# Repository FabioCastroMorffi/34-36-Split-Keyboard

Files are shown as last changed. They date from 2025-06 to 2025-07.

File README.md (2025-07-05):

# Raw Split
## Overview

Raw Split is a wired 36 key split keyboard made with 3 PCB layers and powered by an RP pico 2040 on each side. I'm using the Miryoku ZMK as the layout and  I decided to go for a smaller split keyboard for two main reasons: I want it to be portable, mainly so I can use it in class, and I wanted to be under (or very close to) the 50$ mark.

## Motivation
After finishing my design for Hackpad, which was an introduction to PCB Design and 3D modelling, I was confident I could go build a bigger project in a more efficient manner but I was completely wrong. I got sent to the Valley of Stupidity earlier than expected. 

I had an initial idea with a Split Keyboard that would have magnetic sides but I wasn't proud of the design I came up with (and it wasnt printable) so I decided to scrap it up and do it again with a different idea. The change was mainly on the fact that I abhorred 3D modelling of the top/side and bottom so on the Raw Split I decided to only use PCBs for the full design; the raw aesthetic of the build is where the name comes from -- I'm not very creative with names.

## PCBs

### Center

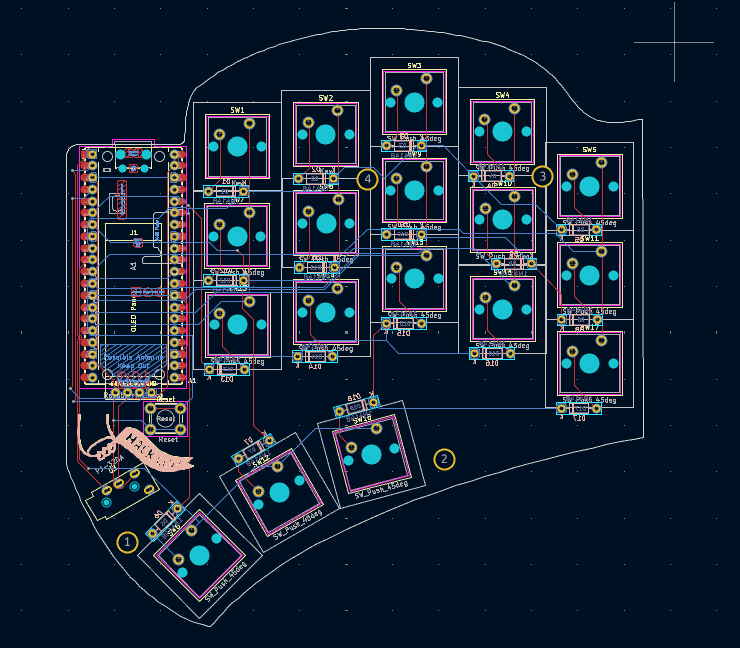
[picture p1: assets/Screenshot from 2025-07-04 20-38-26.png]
Center

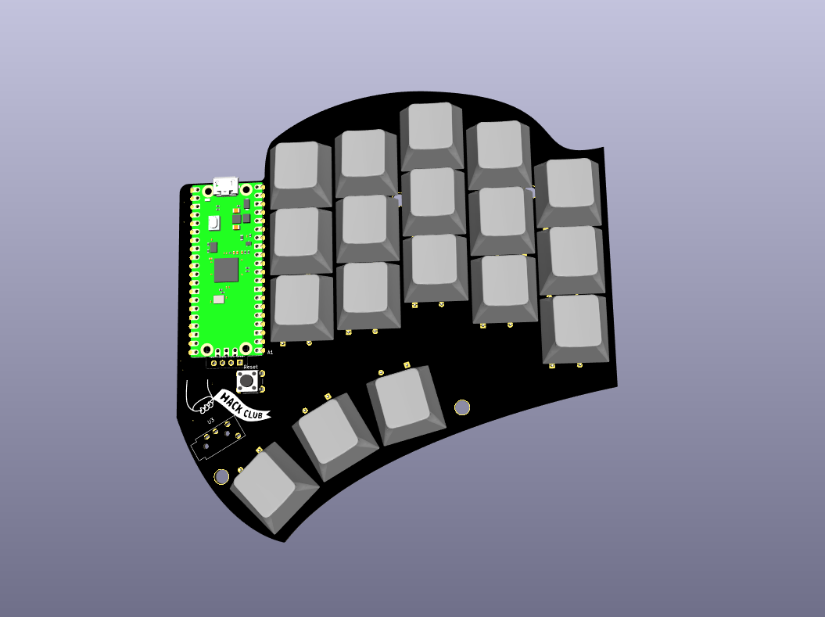
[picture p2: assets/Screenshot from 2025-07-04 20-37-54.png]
3d center


### Top
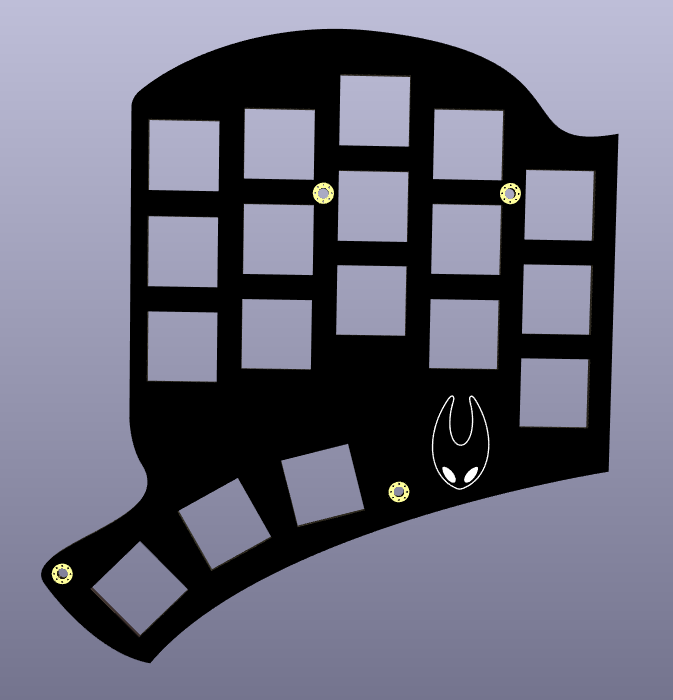
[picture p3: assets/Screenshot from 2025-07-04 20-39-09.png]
Top


### Bottom

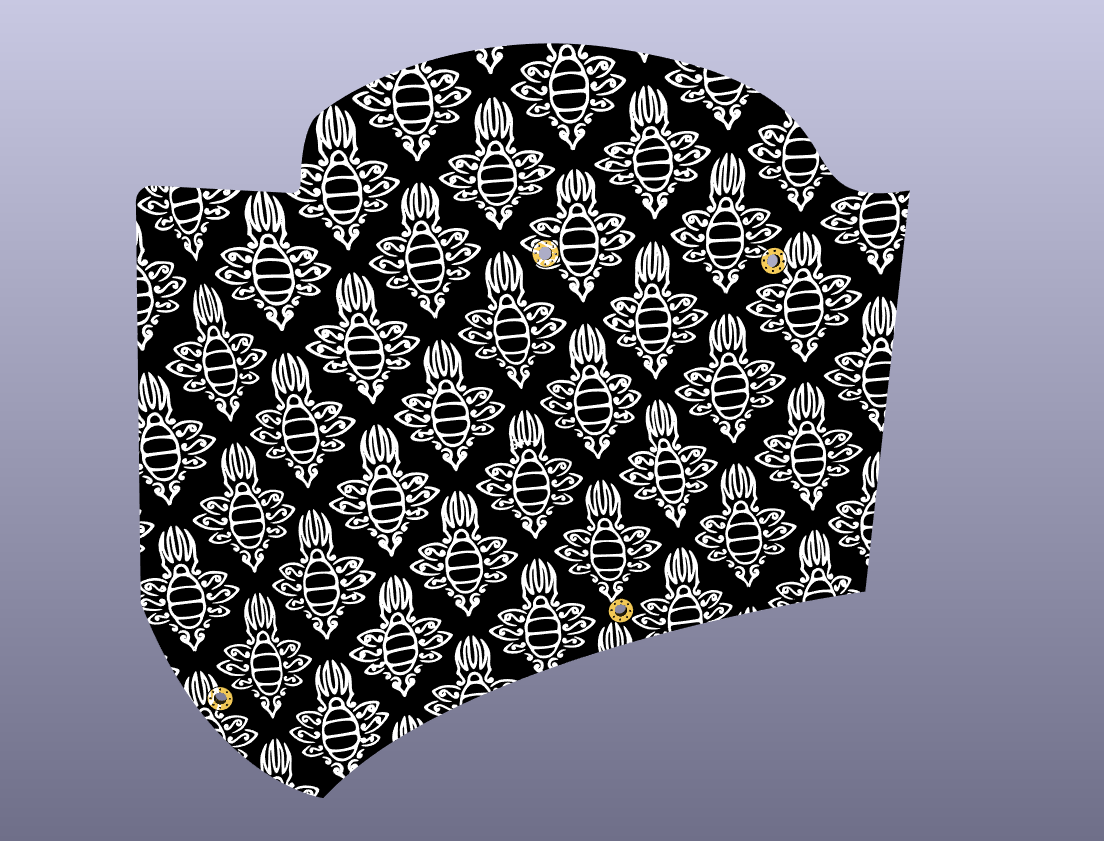
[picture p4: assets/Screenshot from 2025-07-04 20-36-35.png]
Bottom


## CAD
[Direct link on Onshape](https://cad.onshape.com/documents/60adbd5316aad71d4d3bcb16/w/73c77201f5fbc04cf68d7350/e/32bb371216fb4a7634cbbee2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)

Thank you Onshape for being so easy to work with (shame on the horrible experience that is Fusion360's online services for students). I really need to emphasize how much better OnShape is on web, because the initial horrible experience I had with Fusion Online or trying to install a Linux version of Fusion was horrible and made me waste a lot of time. 

Here's the overview of the right split:

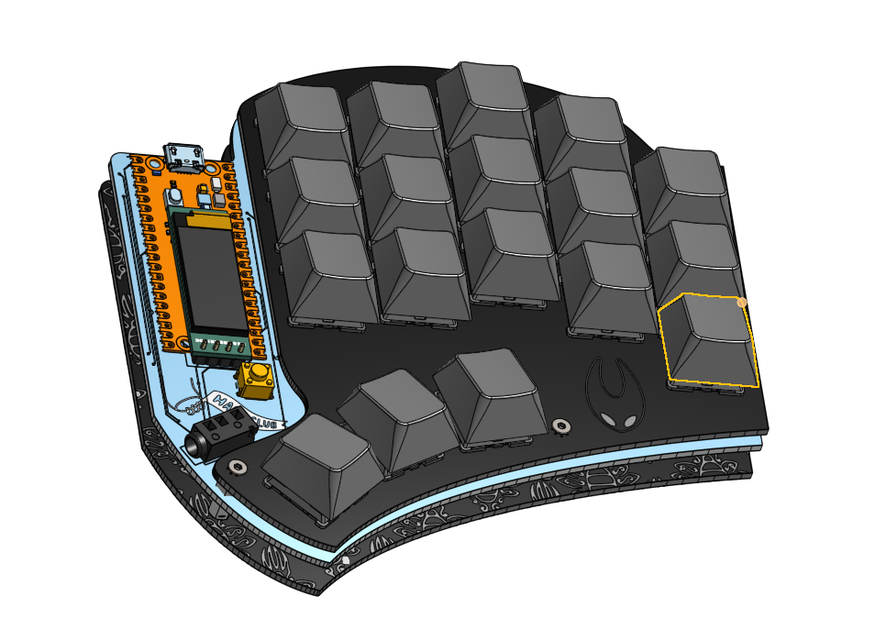
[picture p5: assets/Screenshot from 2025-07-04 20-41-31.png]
Overview


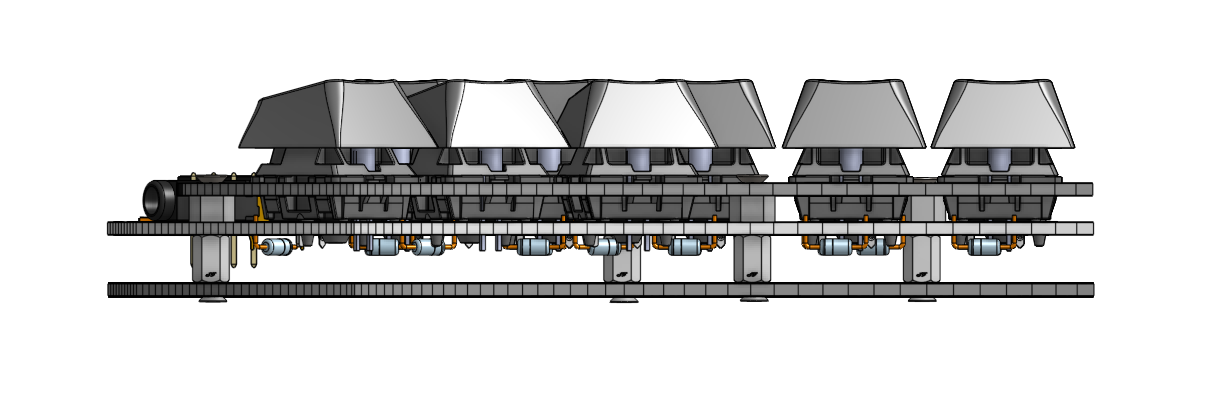
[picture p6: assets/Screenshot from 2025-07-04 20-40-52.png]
Side View


The total height of the keyboard will be 24.8 mm. The three PCBs measure 1.6 mm in height, the small standoff will have a height of 4 mm while the big one will have a size 6 mm. Finally the height from the top plate to the top of the keycap is approximally 10 mm. 

## BOM

| Quantity | Item | Price (CAD) | Vendor | Link |
|---|---|---|---|---|
| 2 | RP Pico 2040 Green with Pin | 6.42 | Aliexpress | [Link](https://shorturl.at/I2swX) |
| 1 | 40 PCS kailh box V2 (linear switches)| 1.38(with welcome deal) | Aliexpress | [Link](https://www.aliexpress.com/item/1005005704076690.html) | 
| 1 | 100 PCS Through Hole Diodes (1N4148) | 2.80 | Aliexpress | [Link](https://shorturl.at/UQSGh) |
| 2 | 0.91 Inch 128x32 Oled Display | 5.00 | Aliexpress | [Link](https://www.aliexpress.com/item/32709141534.html) |
| 2 | 20 pcs Blank DSA Keycaps | 12.5 | Aliexpress | [link](https://shorturl.at/4GHxS) |
| 1 | 10 PCS PJ-320A Jack Receptacle | 1.58 | Aliexpress | [Link](https://www.aliexpress.com/item/1005004960903273.html) |
| 1 | 20 pcs SW-Push 6x6x4.3mm | 0.26 | Aliexpress | [Link](https://shorturl.at/fNnse) |
| 1 | 50 pcs Brass Female to Female Standoffs M2x3mm | 2.72 | Aliexpress | [Link](https://shorturl.at/DMM1S)|
| 1 | 50 pcs Nylon Female to Female Standoffs M2x6mm | 1.28 | Aliexpress | [Link](https://shorturl.at/DEXHc)
| 2 | 50 pcs M2 5mm and M2 10 mm | 4.5 | Aliexpress | [Link](https://shorturl.at/Y6ADS) |
| 1 | Antislip Circular Pads 2mm | 2.97 | Aliexpress | [Link](https://shorturl.at/uavc9)
| 1 | PCB Manufacturing Center | 13.04  (without coupon) | JLCPCB | 
| 1 | PCB Manufacturing Top | 12.64  (without coupon) | JLCPCB |
| 1 | PCB Manufacturing Bottom | 12.50  (without coupon) | JLCPCB |

|Total (CAD, after taxes and after 20$ JLcPCB Coupon)| Total (USD, after taxes and after 20$ JLcPCB Coupon)|
|---|--|
|69|50.69|

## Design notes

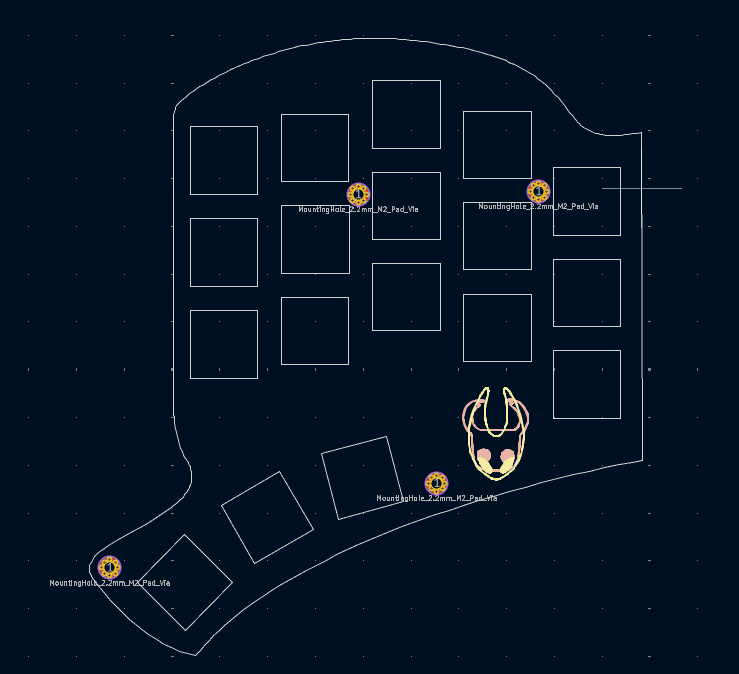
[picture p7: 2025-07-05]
assets/Screenshot from 2025-07-04 20-39-25.png

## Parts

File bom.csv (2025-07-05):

Quantity | Item | Price (CAD) | Vendor | Link | Total(CAD after taxes and after 20$ JLPCB Coupon) | Total(USD after taxes and after 20$ JLcPCB Coupon)
2 | RP Pico 2040 Green with Pin | 6.42 | Aliexpress | https://shorturl.at/I2swX
1 | 40 PCS kailh box V2 (linear switches) | 1.38 (with welcome deal) | Aliexpress | https://www.aliexpress.com/item/1005005704076690.html
1 | 100 PCS Through Hole Diodes (1N4148) | 2.80 | Aliexpress | https://shorturl.at/UQSGh
2 | 0.91 Inch 128x32 Oled Display | 5.00 | Aliexpress | https://www.aliexpress.com/item/32709141534.html
2 | 20 pcs Blank DSA Keycaps | 12.5 | Aliexpress | https://shorturl.at/4GHxS
1 | 10 PCS PJ-320A Jack Receptacle | 1.58 | Aliexpress | https://www.aliexpress.com/item/1005004960903273.html
1 | 20 pcs SW-Push 6x6x4.3mm | 0.26 | Aliexpress | https://shorturl.at/fNnse
1 | 50 pcs Brass Female to Female Standoffs M2x3mm | 2.72 | Aliexpress | https://shorturl.at/DMM1S
1 | 50 pcs Nylon Female to Female Standoffs M2x6mm | 1.28 | Aliexpress | https://shorturl.at/DEXHc
2 | 50 pcs M2 5mm and M2 10 mm | 4.5 | Aliexpress | https://shorturl.at/Y6ADS
1 | Antislip Circular Pads 2mm | 2.97 | Aliexpress | https://shorturl.at/uavc9
1 | PCB Manufacturing Center | 13.04 (without coupon) | JLCPCB
1 | PCB Manufacturing Top | 12.64 (without coupon) | JLCPCB
1 | PCB Manufacturing Bottom | 12.50 (without coupon) | JLCPCB
 |  |  |  |  | 69 | 50.69

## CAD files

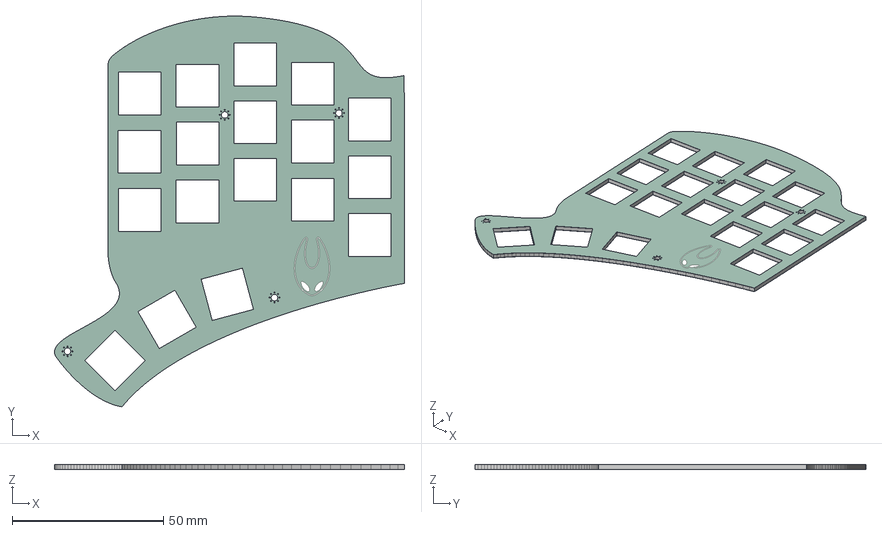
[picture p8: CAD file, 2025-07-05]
PCB/3d models/top.step
115.7 x 129.2 x 1.66 mm
top_silkscreen
top_soldermask
top_PCB

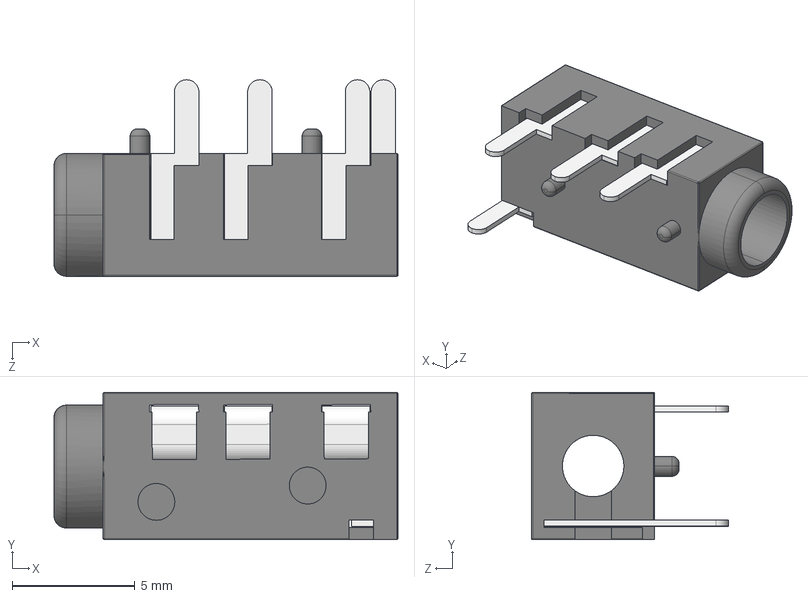
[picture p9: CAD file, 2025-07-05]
PCB/raw split center/3d models/PJ320A.STEP
14.0 x 6.00 x 8.00 mm
PJ320A
PJ320A-Pin x 3
PJ320A-Pin-B

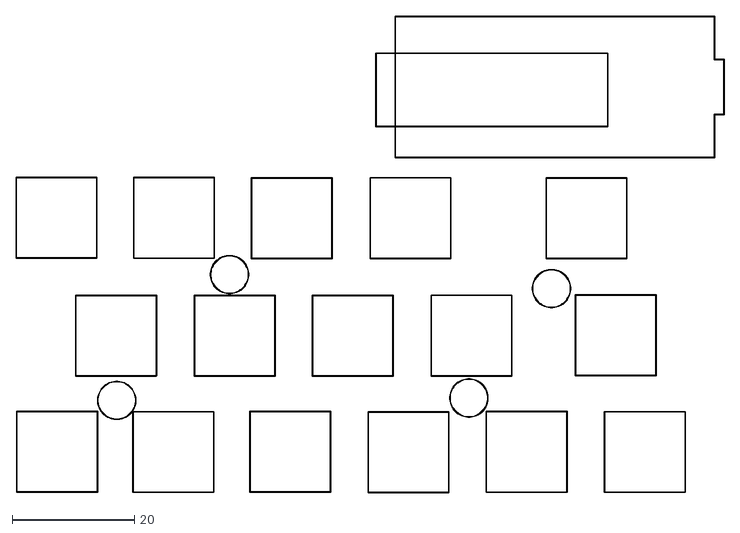
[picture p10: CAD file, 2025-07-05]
PCB/raw split center/custom_Hackboard-F_Courtyard.dxf
116.0 x 78.0

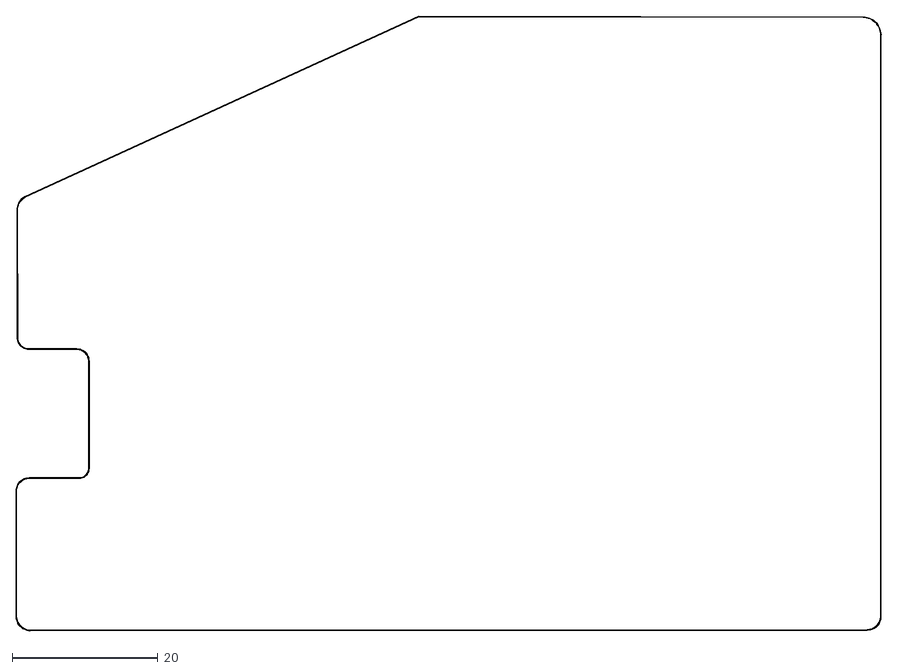
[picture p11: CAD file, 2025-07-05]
PCB/raw split center/custom_Hackboard-Edge_Cuts.dxf
118.8 x 84.4

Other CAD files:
PCB/raw split center/custom_Hackboard-User_Eco2.dxf

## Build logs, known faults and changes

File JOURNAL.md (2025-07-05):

---
title: "Raw Split"
author: "Fabio"
description: "36 Key Split Keyboard with three layers of PCB"
created_at: "2025-06-05"
---
# Important

The orginal idea for the design was redesigned, here's an internal link to the current one: 
[Jump to Current Design](#july-4th-2025---big-change)

## Total Time: Too Much
## June 6th 2025 - Initial idea

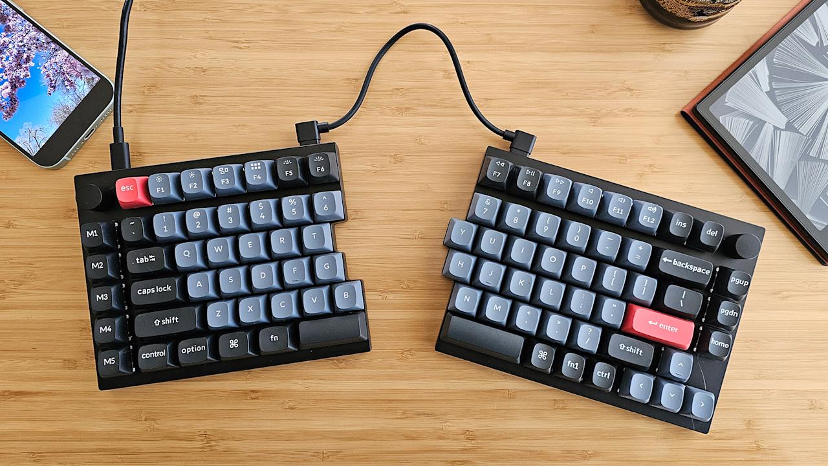
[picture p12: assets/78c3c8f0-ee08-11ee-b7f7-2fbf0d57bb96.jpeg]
Split Keebs that could be joined
I've wanted to build a split keyboard for some time but with an additional twist, something (slightly) unique to it. After brainstorming a for a little while, I found I wanted an original design that had something to do with magnets (Love magnets!). Watching projects such as this one 

I thought about a split keyboard that could become a single one with magnets and perhaps trigger something on OLED screens with the use of Hall Effect Sensors(not sure at all about this but we'll see as we progress).

Most of the time today was me thinking about this idea, but I also started doing the schematics of the pcb. I'm thinking of going for a wired build using RP Pico 2040 as the microcontrollers and using TRRS Jack for the communitcation between the two sides. The rest of the components are the 2 OLED screens 0.91, some cheap **CLICKY** switches and the diodes that go with them.

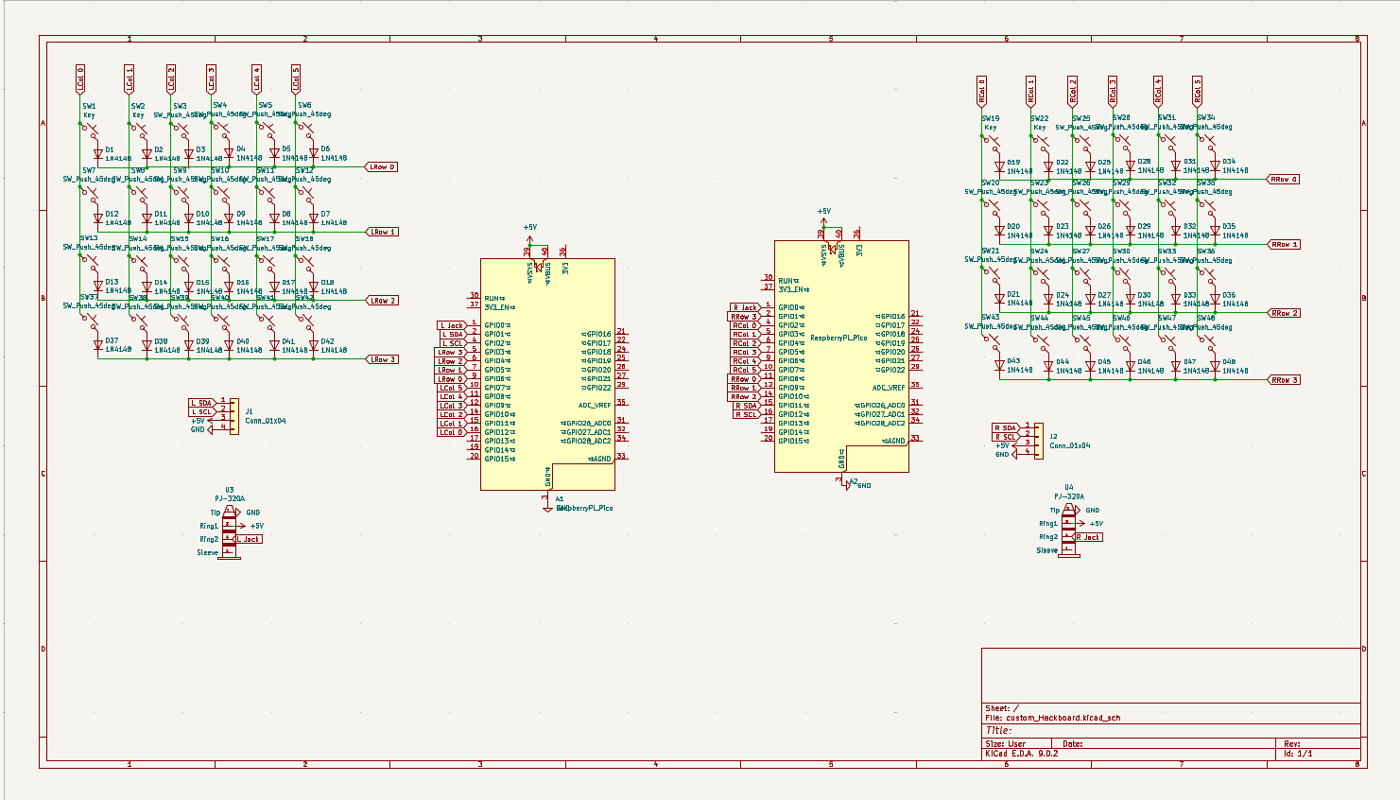
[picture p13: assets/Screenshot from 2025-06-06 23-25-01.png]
PCB Schematics


### Futur Challenges

- The design of the case to best fit the magnets will probably prove to be difficult(not to talk about type of magnet, shape, etc)
- Using the Hall Effect Sensors to check whether the two halfs are connected is something I'm not even sure at the moment that could work

### <span style="color:green">Time Spent</span>: 5h(Again, today was mostly research)

## June 10th 2025 - Draft PCB layout

Had to take a break but today I'm back on the grind. I downsized the splitkeyboard to have a total of 36 keys rather than 48. The main reason behind this is that I feel the extra keys wouldn't really make a difference since the intention is to mainly write text with this keyboard. 

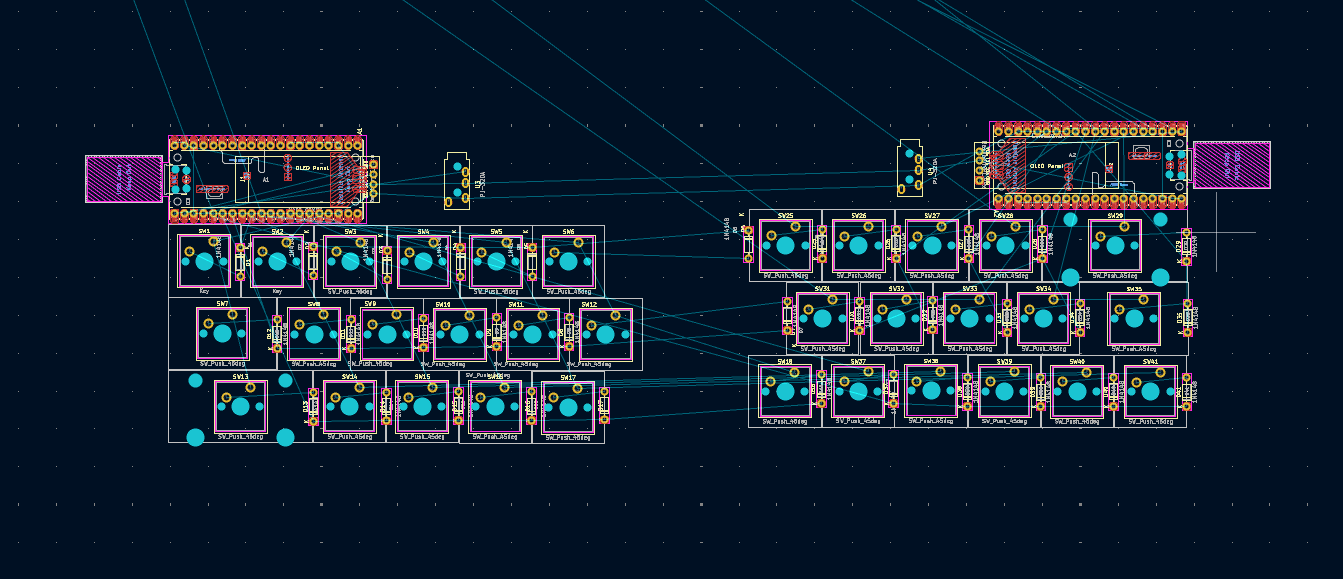
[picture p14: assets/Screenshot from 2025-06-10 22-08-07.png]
PCB Draft .pcb file


Taking ideas from examples online(such as the [Lily58](https://github.com/FabioCastroMorffi/Magnetic-Split/blob/main/assets/84393842-13960900-ac37-11ea-811e-65db2948ca73.jpg)), I decided to go with the layout where the OLED Screen stands on top of the MCU to help with space management (and cause it also looks cool). This could cause problems if I ever need access to what's covered by the OLED screen but, since I didn't cover the main buttons, I don't think it's something to really worry about. 

### Time Spent: 1 hour (Tomorrow big update for sure!)

## June 11th 2025 - Finished PCB Layout

Today was a 'getting things done session'. I settled on the asymetric design for the split (Hopefully it fits budget, fingers crossed)and spent some time working on the size of the PCB as well on the routing (god the routing was insane). I also added the 3d models for all components and some art as well.

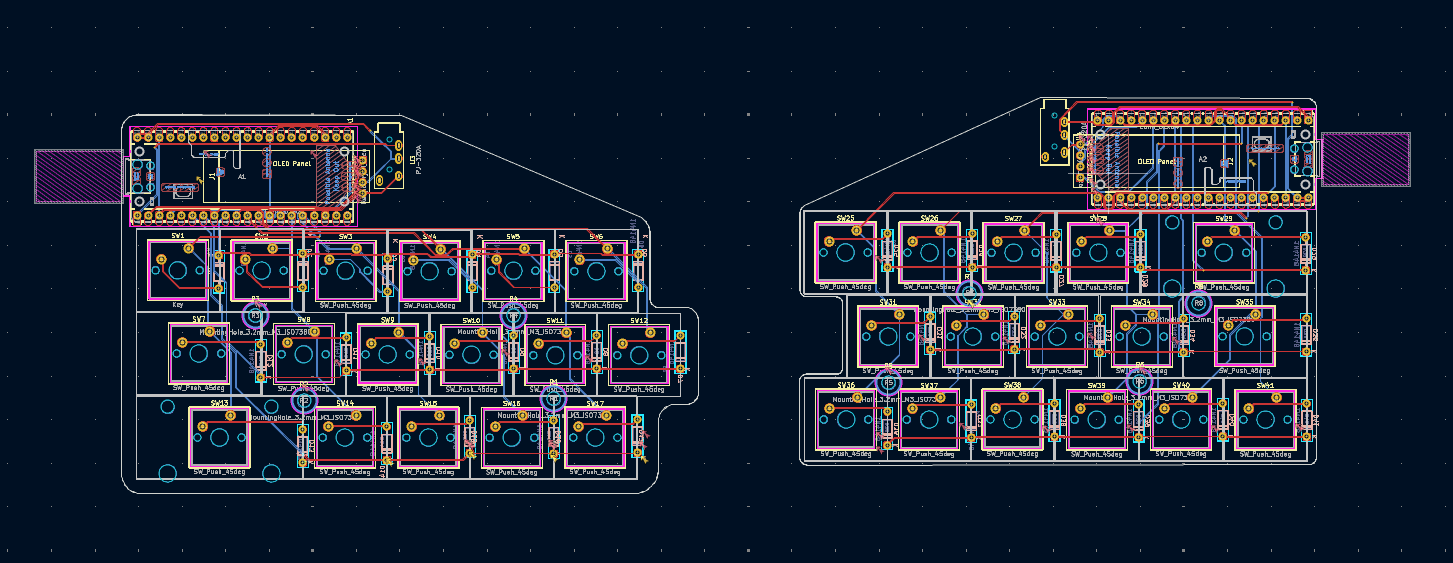
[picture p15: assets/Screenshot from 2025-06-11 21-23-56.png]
Finished PCB


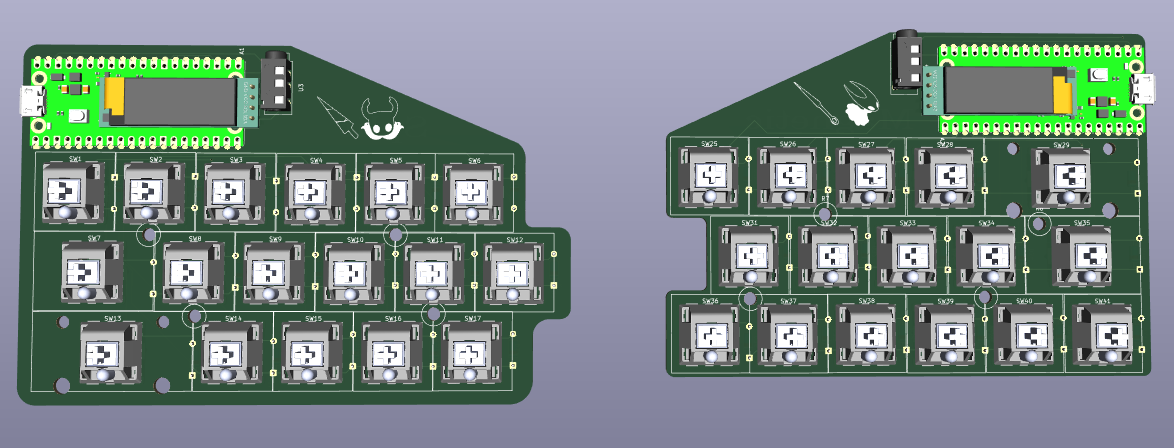
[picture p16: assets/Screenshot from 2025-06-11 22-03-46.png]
3d Models and Art


Crazy to think that in 1 paragraph I resumed 5 hours of work (rounding down) so here are some of the taks that took a lot of time to get through:

- Changing the 3D model of an existing footprint (with the objective of saving time with the switches) and applying said footprint to all switches at one (ended up having to apply it one by one in schematics)
- Adjusting arc length when doing round lines in EdgeCuts; It is hard for me to believe that using the arc tool is the best way to do this.
- Adding art to my PCB. This one is completely on me. It took me a lot of time to catch that the Bit2MapConverter was already featured in the main menu of KiCad. I spent most of my time looking for inexistent plugin or software to do this until I found it.
- Last but not least, Routing. This one is one everyone can agree in. At the start, the space between my the edge of my PCBs and the components was too small so I couldn't get around with a track. Had to change the lines in EdgeCuts twice before finishing routing.

### Time Spent: 5 hours (Starting Designs on CAD Tomorrowww)

## June 14th 2025 - The CAD

Finally working on the keebs again!! Today was a rough session cause of Fusion 360. It is infuriating that this software is only available natively in Windows and Mac. Yes, there are some workarounds for Linux users, but I can assure you I tried the main ones and they didnt work at all. So yeah, today I had the long overdue change from the HORRIBLE Fusion 360 browser experience to Onshape. Even though it took me some time to get the hang of it, the transition is not that bad. 

Here are some pictures of the top of my case with the STEP file of my PCB which are the main parts that I worked on today.

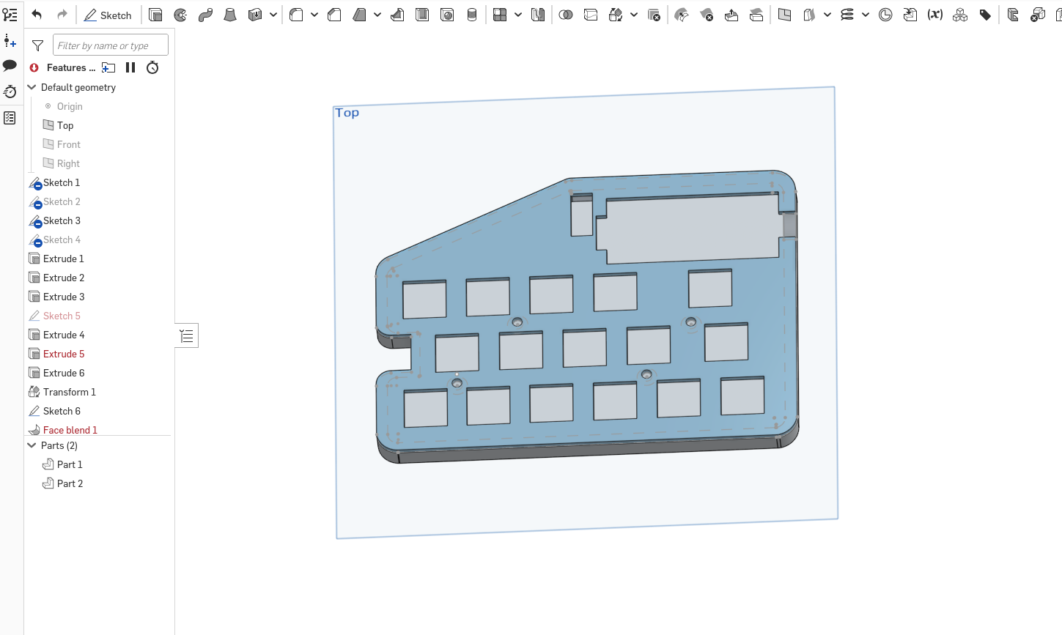
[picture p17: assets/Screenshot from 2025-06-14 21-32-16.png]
CAD Top case


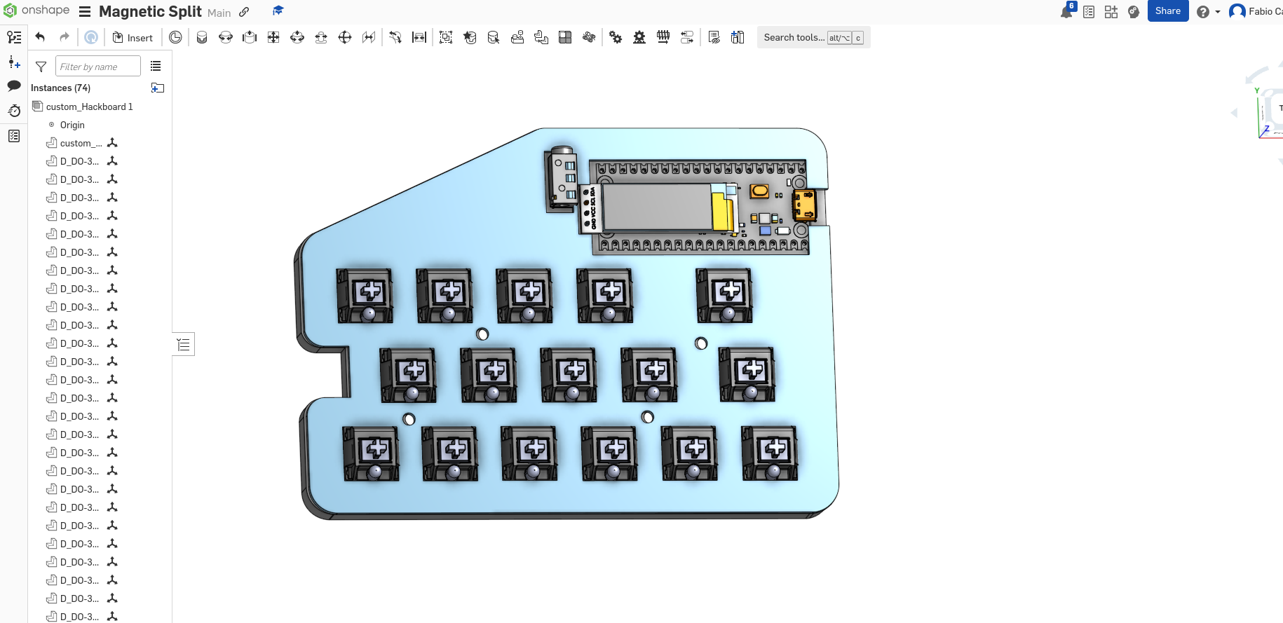
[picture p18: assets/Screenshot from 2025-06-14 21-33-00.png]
CAd top with 3d pcb


Quite bad right? Keep in my mind it's my second ever hardware project; We all start somewhere. Now on a more serious manner, these are some of the points that I need to improve or start working on for the following session. 

- Holes' alignment. The holes for the jack receptor, the mounting holes and the switches are not perfectly aligned with the pcb (If i've learned something from using KiCad is not 100% trust the exported DXF images cause the measurements are not exact, maybe im doing it wrong)
- The top case has ugly sharp corners. I could use the chamfer tool to improve that part and fillet for like the microusb entrance for the RPs
- Add the holes for the magnets to fit in. Since the keyboards will be pretty light, I believe 10x3 mm cylindrical Neodyum Magnets will do the trick (3 of them in each keyboard)
- Create a bottom case for the keyboard (I'm starting to panic with the amount of plastic for these two splits with the budget)
- Duplicate this with the second one (work on the puzzle feeling between the right one and the left one)

Thinking it through, the magnet is nothing but a gimmick, snake oil, on a project that is actually just a split wired keyboard, but well we've come this far I guess we'll keep going. 

### Time spent: 6 hours 

## June 17th 2025- The CAD (Part 2)

I spent the last three days both fixing( and breaking) stuff; in fact, the reason I didn't separate today's journal into two parts is because I was furious yesterday thinking I had lost some very important changes. This is a great opportunity to say: 'God bless **Version Control**'. Due to an involontary change I made that I only caught later on, I had to restore my build to a much older version. This unfortunately implied I had to lose some of the progress I had made (or not??, if theres a way, I didnt find it) in order to fix that error (still better than having to fix all of it). This made me lose some time, but, in retrospective, it was a great learning experience.

## Main improvements:

- [x] Holes are alligned.
- [x] Used chamfer and fillet on some edges to diminish sharp, ugly corners.
- [x] Added a male/female receptacles as well as the magnets holes (4 Neodyum Magnets will be used with dimensions 5x2mm, due to the small weight of the case it should be enough).
- [x] Created the bottom case for the keyboard.
- [x] Made the right half(mainly with the mirroring tool).

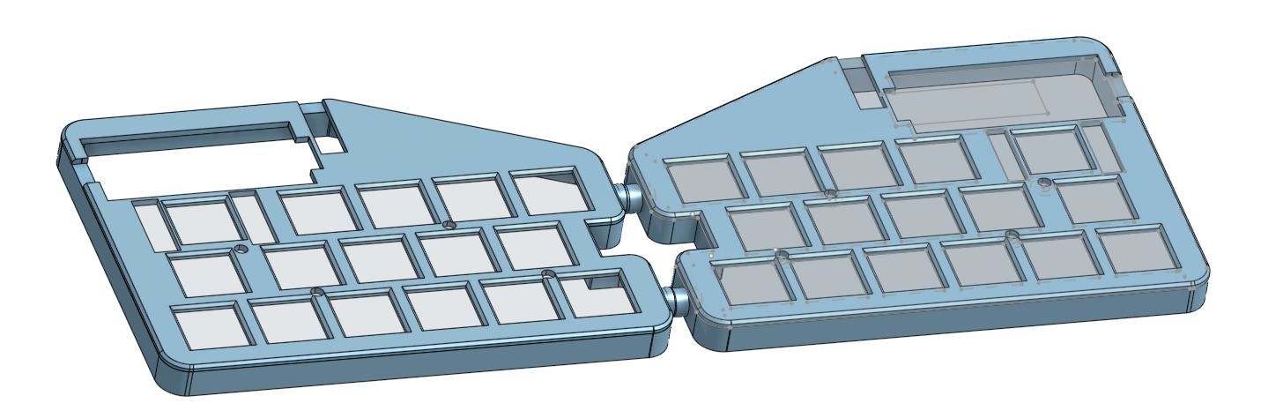
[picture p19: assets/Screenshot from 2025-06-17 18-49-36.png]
Joining CAD splits


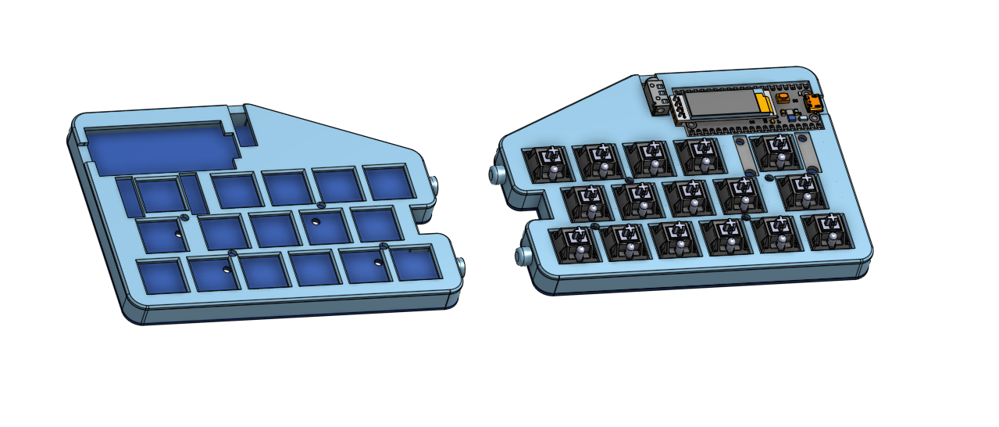
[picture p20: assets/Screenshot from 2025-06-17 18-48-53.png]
With 3d PCB


## What's missing?

- Finishing GitHub (uploading files, updating README and BOM, etc)
- Make post on #highway-pitstop and complete form
- Maybe have to change it because its not complex enough, maybe(I think its the 3d design is not that bad)

### Time Spent: 8 hours (Getting ready to ship tomorrowww)

## July 4th 2025 - Big Change

After a long break, I went and took a look at were I left the project a couple of weeks ago and I was .... disappointed with how it turned out. The top of the 3D model had to be changed because it wasn't printable, the design looked bland and the key layout didn't appear as appealing as the first day. What did I do to improve that? I spent the last three days redesigning everything (basically started a new project) and I told myself I would attempt not to use 3D modeling because of how **miserable** 3D modeling felt (manually changing the svg files, once imported, because measurements were off was an aboslute nightmare).

But here we are! with a design I kinda like were I basically replaced the 3d printed top and bottom for PCB plates which gives it more of a raw appearance. I also went with a more traditional (and useful!) key layout prioritizing ergonomy.

## PCBs

### Main PCB

Center
3d center

### Top Plate
Top

### Bottom Plate
Bottom

## Assembled 3D Model (imported everything into Onshape)
### Overview

Overview

### Side View

For the 3 plates to be connected, I'll use 8 standoffs(4x M2 3mm and 4x M2 6mm). The small ones are for connecting the top and the center and the big ones are for connecting the bottom and the center. In addition, the M2 screws I'll use are 4 M2 10mm and 4 M2 4mm.

Side View

In order to equilibrate height, I will also add antislip pads on the bottom plate.

### Time Spent: ~20 hours

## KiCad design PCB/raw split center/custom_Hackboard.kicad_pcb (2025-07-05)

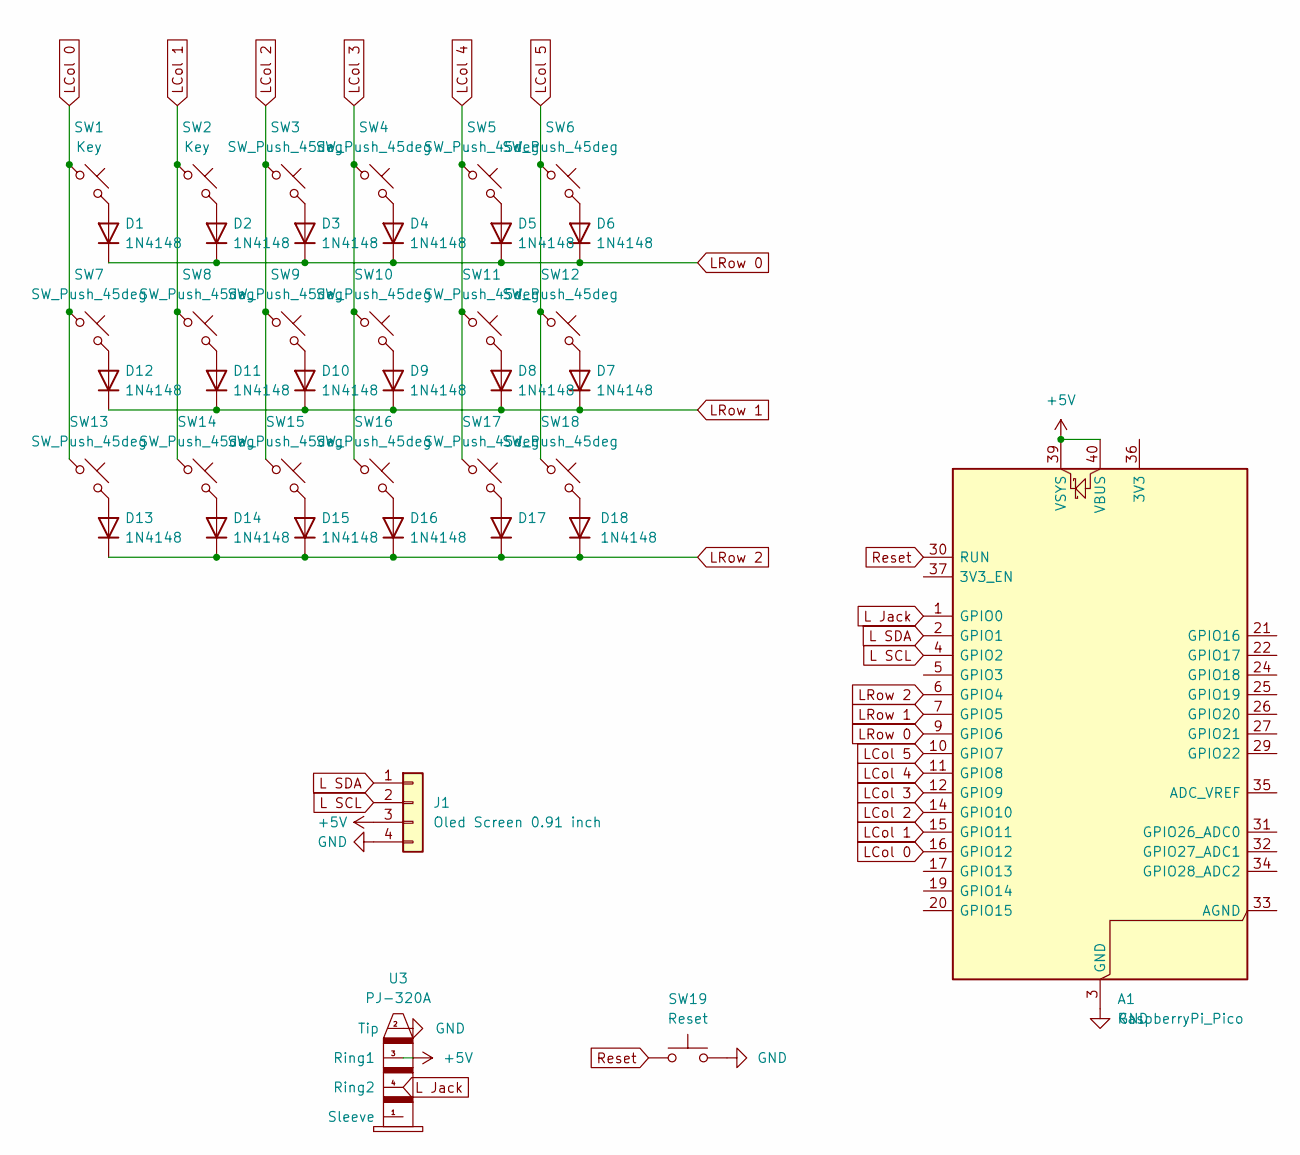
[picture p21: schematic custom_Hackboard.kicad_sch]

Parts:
A1: RaspberryPi_Pico; RaspberryPi_Pico_Common_Unspecified
D1, D2, D3, D4, D5, D6, D7, D8, D9, D10, D11, D12, D13, D14, D15, D16, D17, D18: 1N4148; D_DO-35_SOD27_P7.62mm_Horizontal
J1: Oled Screen 0.91 inch; SSD1306-0.91-OLED-4pin-128x32
SW1, SW2: Key; Cherry MX 1u
SW3, SW4, SW5, SW6, SW7, SW8, SW9, SW10, SW11, SW12, SW13, SW14, SW15, SW16, SW17, SW18: SW_Push_45deg; Cherry MX 1u
SW19: Reset; SW_PUSH_6mm_H5mm
U3: PJ-320A

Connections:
+5V: A1.39 (VSYS), A1.40 (VBUS), J1.3, U3.3 (Ring1)
GND: A1.3 (GND), A1.8 (GND), A1.13 (GND), A1.18 (GND), A1.23 (GND), A1.28 (GND), A1.38 (GND), J1.4, SW19.2, U3.2 (Tip); also elsewhere on the board
L Jack: A1.1 (GPIO0), U3.4 (Ring2)
L SCL: A1.4 (GPIO2), J1.2
L SDA: A1.2 (GPIO1), J1.1
LCol 0: A1.16 (GPIO12), SW1.1, SW7.1, SW13.1
LCol 1: A1.15 (GPIO11), SW2.1, SW8.1, SW14.1
LCol 2: A1.14 (GPIO10), SW3.1, SW9.1, SW15.1
LCol 3: A1.12 (GPIO9), SW4.1, SW10.1, SW16.1
LCol 4: A1.11 (GPIO8), SW5.1, SW11.1, SW17.1
LCol 5: A1.10 (GPIO7), SW6.1, SW12.1, SW18.1
LRow 0: A1.9 (GPIO6), D1.1 (K), D2.1 (K), D3.1 (K), D4.1 (K), D5.1 (K), D6.1 (K)
LRow 1: A1.7 (GPIO5), D7.1 (K), D8.1 (K), D9.1 (K), D10.1 (K), D11.1 (K), D12.1 (K)
LRow 2: A1.6 (GPIO4), D13.1 (K), D14.1 (K), D15.1 (K), D16.1 (K), D17.1 (K), D18.1 (K)
unnamed: D1.2 (A), SW1.2
unnamed: D2.2 (A), SW2.2
unnamed: D3.2 (A), SW3.2
unnamed: D4.2 (A), SW4.2
unnamed: D5.2 (A), SW5.2
unnamed: D6.2 (A), SW6.2
unnamed: D7.2 (A), SW12.2
unnamed: D8.2 (A), SW11.2
unnamed: D9.2 (A), SW10.2
unnamed: D10.2 (A), SW9.2
unnamed: D11.2 (A), SW8.2
unnamed: D12.2 (A), SW7.2
unnamed: D13.2 (A), SW13.2
unnamed: D14.2 (A), SW14.2
unnamed: D15.2 (A), SW15.2
unnamed: D16.2 (A), SW16.2
unnamed: D17.2 (A), SW17.2
unnamed: D18.2 (A), SW18.2
Reset: A1.30 (RUN), SW19.1; also elsewhere on the board

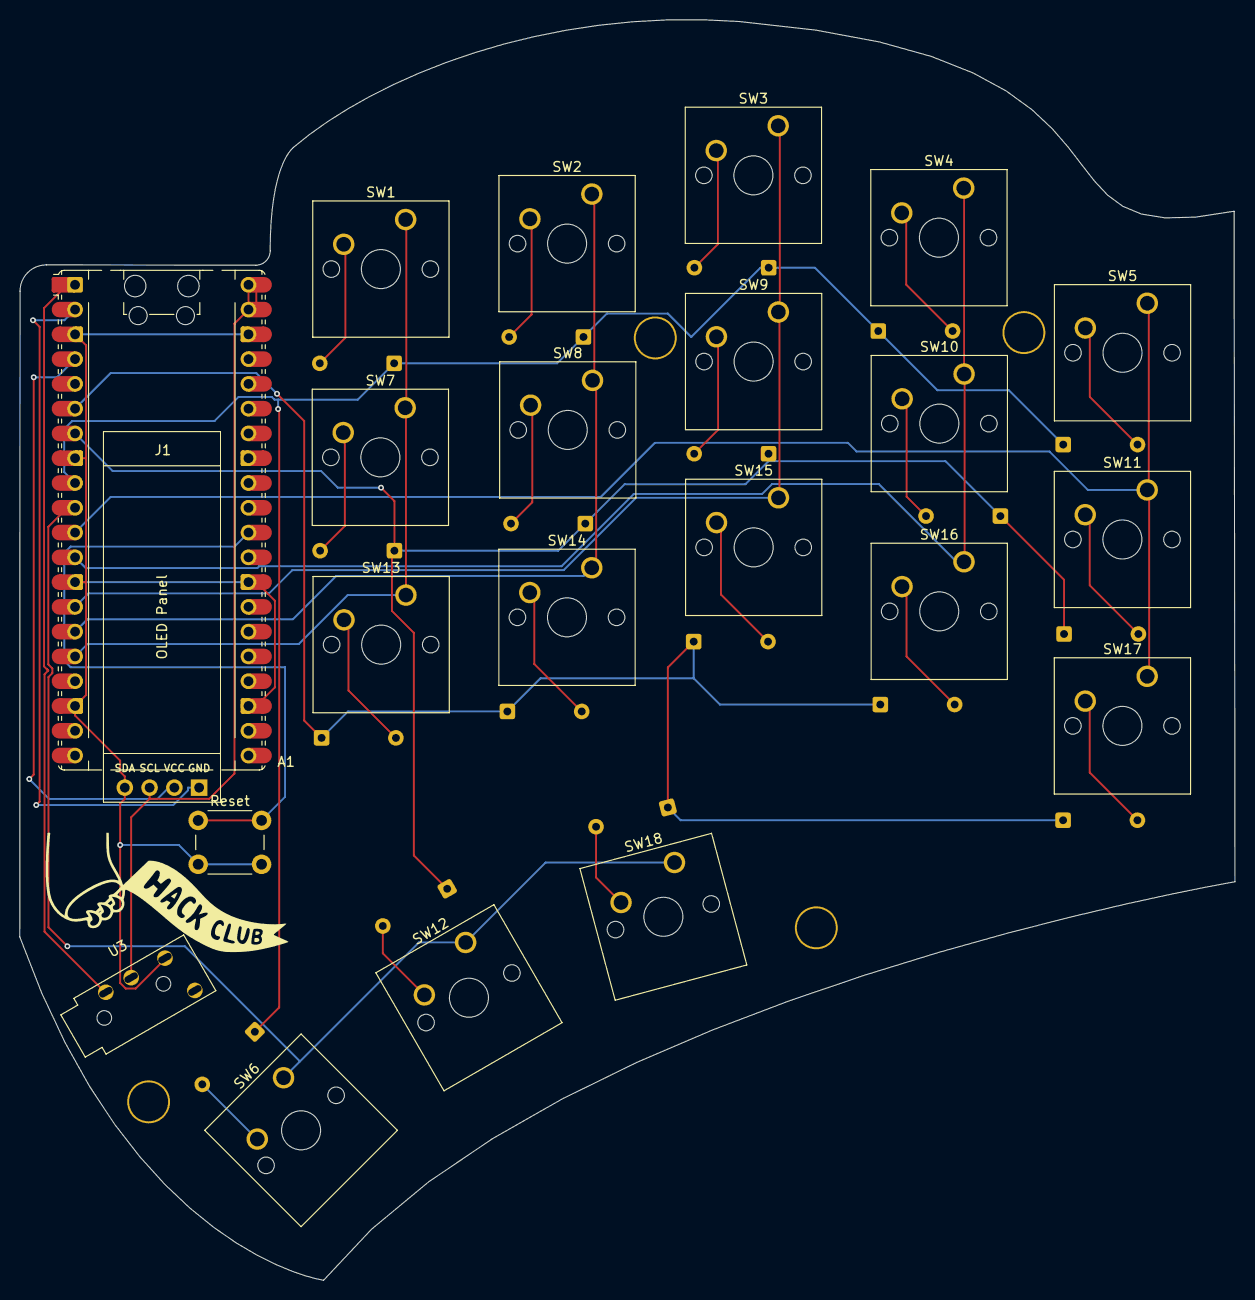
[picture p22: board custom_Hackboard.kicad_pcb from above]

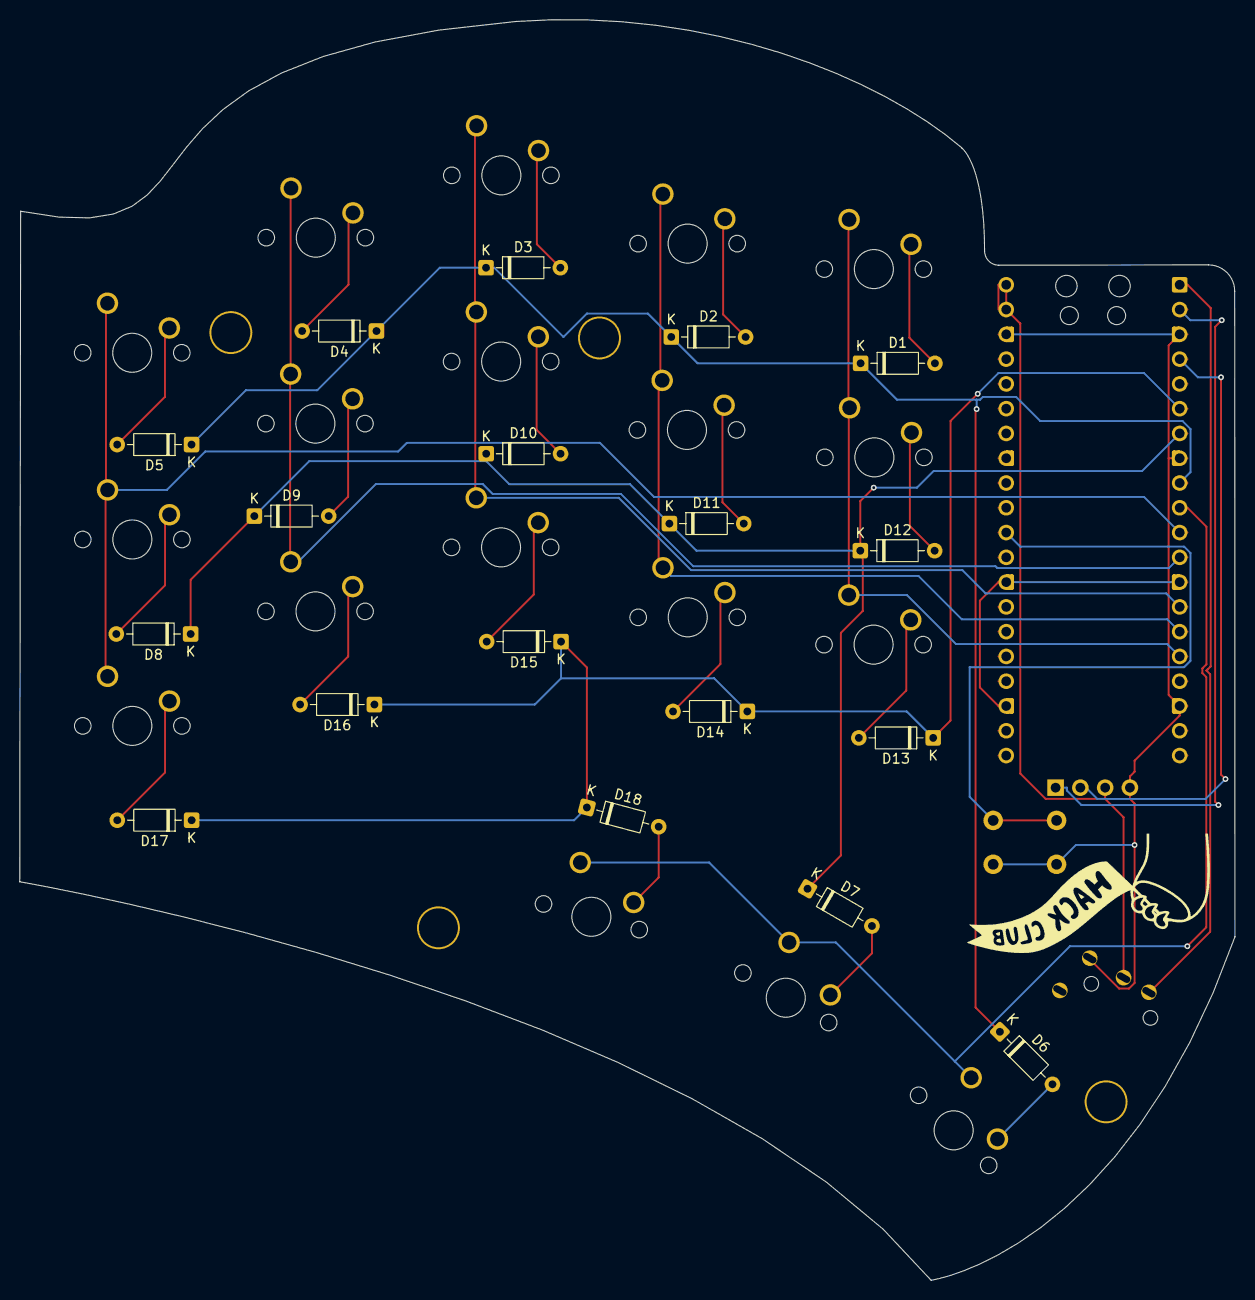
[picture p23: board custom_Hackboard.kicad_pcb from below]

Board: 2 copper layers, 124.6 x 129.2 mm, 42 parts (19 on the bottom side), 33 nets.

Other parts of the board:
  : LOGO; hackclub
  #2: LOGO; hackclub
Reset: Reset; SW_PUSH_6mm_H5mm

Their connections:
GND: Reset.2; also elsewhere on the board
Reset: Reset.1; also elsewhere on the board

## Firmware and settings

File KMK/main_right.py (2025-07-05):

import board
import displayio
import terminalio
import busio

from kb import KMKKeyboard
from kmk.scanners import DiodeOrientation
from kmk.keys import KC
from kmk.modules.layers import Layers
from kmk.modules.split import Split, SplitSide, SplitType

from adafruit_display_text import label
from adafruit_ssd1306 import SSD1306_I2C

keyboard = KMKKeyboard()

# Pins
keyboard.col_pins = (board.GPIO12, board.board.GPIO11, board.GPIO10, board.GPIO9, board.GPIO8, board.GPIO7)
keyboard.row_pins = (board.GPIO6, board.GPIO5, board.GPIO4)
keyboard.diode_orientation = DiodeOrientation.COL2ROW

#Oled for text display

displayio.release_displays()
i2c = busio.I2C(board.GPIO1, board.GPIO2)  # might reverse SDA and SCL if incorrect

display = SSD1306_I2C(38, 12, i2c)
splash = displayio.Group()

text_area = label.Label(terminalio.FONT, text="RAW SPLIT", x=2, y=10)
splash.append(text_area)
display.show(splash)


# Split Side
split_side = SplitSide.RIGHT


split = Split(split_type=SplitType.UART, split_side=split_side)

layers = Layers()

keyboard.modules = [layers, split]

# Key's reassignment

_______ = KC.TRNS



LOWER = KC.MO(2)
RAISE = KC.MO(1)


# fmt:off
keyboard.keymap = [
    [  #QWERTY
        KC.Q,    KC.W,    KC.E,    KC.R,    KC.T,                         KC.Y,    KC.U,    KC.I,    KC.O,   KC.P,
        KC.A,    KC.S,    KC.D,    KC.F,    KC.G,                         KC.H,    KC.J,    KC.K,    KC.L, KC.SCLN,
        KC.Z,    KC.X,    KC.C,    KC.V,    KC.B,                         KC.N,    KC.M, KC.COMM,  KC.DOT, KC.SLSH,
                                    KC.LCTL,   LOWER,  KC.SPC,     KC.BSPC,    RAISE,  KC.ENT,
    ],
    [  #RAISE
        KC.N1,   KC.N2,   KC.N3,   KC.N4,   KC.N5,                        KC.N6,   KC.N7,   KC.N8,   KC.N9,   KC.N0,
        KC.TAB,  KC.LEFT, KC.DOWN, KC.UP,   KC.RGHT,                      KC.NO, KC.MINS, KC.EQL,  KC.LBRC, KC.RBRC,
        KC.LCTL, KC.GRV,  KC.LGUI, KC.LALT, KC.NO,                      KC.NO, KC.NO, KC.NO, KC.BSLS, KC.QUOT,
                                    KC.NO, KC.NO, KC.NO,      KC.NO, KC.NO, KC.NO,
    ],
    [  #LOWER
        KC.EXLM, KC.AT,   KC.HASH, KC.DLR,  KC.PERC,      KC.CIRC, KC.AMPR, KC.ASTR, KC.LPRN, KC.RPRN,
        KC.ESC,  KC.NO, KC.NO, KC.NO, KC.NO,      KC.NO, KC.UNDS, KC.PLUS, KC.LCBR, KC.RCBR,
        KC.CAPS, KC.TILD, KC.NO, KC.NO, KC.NO,      KC.NO, KC.NO, KC.NO, KC.PIPE,  KC.DQT,
                            KC.NO, KC.NO, KC.NO,      KC.ENT,  KC.NO, KC.DEL
    ]
]
# fmt:on

if __name__ == '__main__':
    keyboard.go()

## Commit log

2025-06-18 finished CAD design, missing finishing
2025-06-18 adding PCB, 3d model, KMK and finishing README
2025-07-05 added pcb files and removed som directories
    [BottomL.step, BottomR.step, CaseL.step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]
2025-07-05 replaced bom csv
    [BOM.csv, bom.csv]
